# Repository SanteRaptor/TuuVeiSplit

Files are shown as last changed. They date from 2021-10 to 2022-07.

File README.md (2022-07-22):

# TuuVeiSplit v1.0 and v1.5 "Deluxe" 

A non-symmetrical non-standard (2x y & h with a b on the left side) TRRS split TKL keyboard with Vial support and ISO layout

Repository contains:

-Case STLs with extras

-Kicad PCB project files

-Firmware hex files

-QMK required files

-VIAL Json file

-PCB STL

-GERBERS!

(both versions compatible with eachothers parts)

Uses 2 arduino pro micros (or alternatives), 2 trough-hole TRRS ports and a TRRS cable for connecting the sides, trough-hole or smd 1n4148 diodes, 5 2U PCB stabilizers and 2 trough-hole resistors (chose to use 7.4k 1w but less wattage is fine).

Both versions tested to be fully working and keyboards have been built accordingly

Images

V1.5



V1.0



Acrylic case


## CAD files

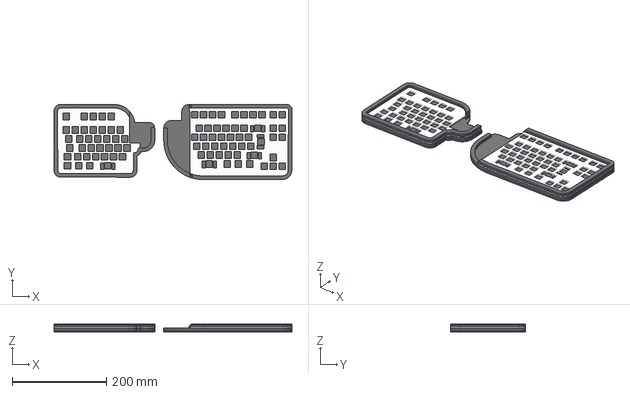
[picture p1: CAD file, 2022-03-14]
acryliccase.step
504.6 x 159.5 x 18.0 mm

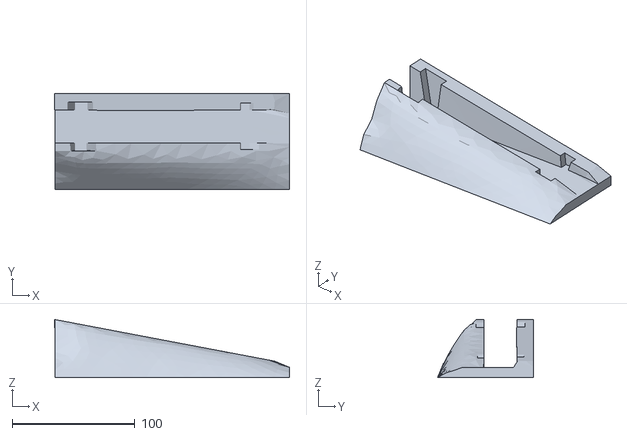
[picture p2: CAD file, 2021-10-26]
TUUVEICASE/Tuuright.stl
191.8 x 78.5 x 47.4

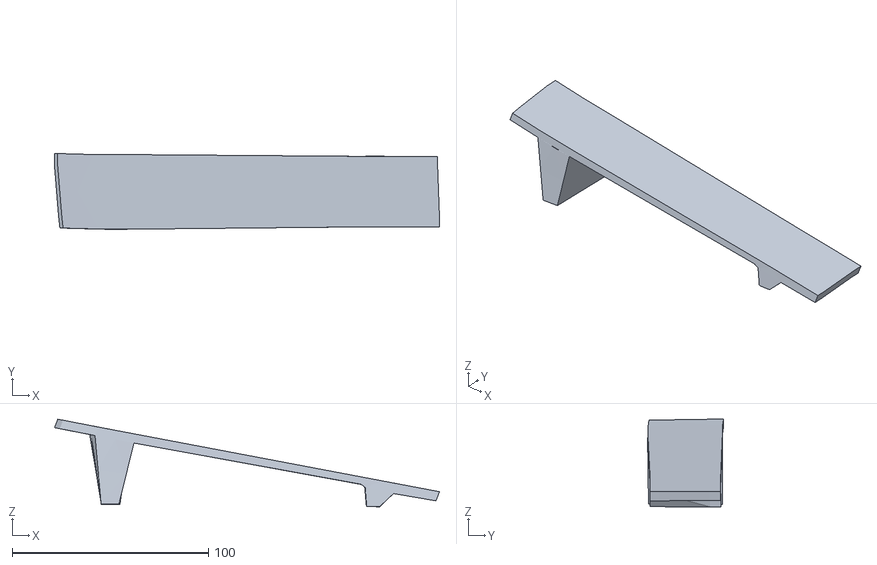
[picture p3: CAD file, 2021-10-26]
TUUVEICASE/TUUTUURIGHT.stl
196.4 x 38.7 x 44.7

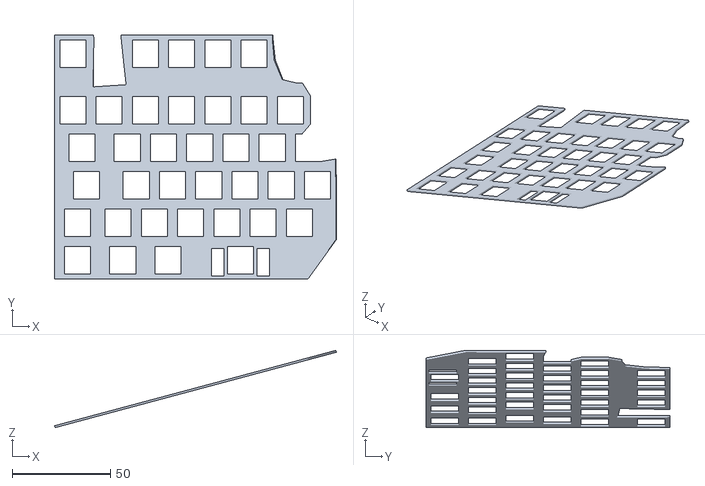
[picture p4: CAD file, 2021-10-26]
TUUVEICASE/plateleft.stl
143.2 x 123.8 x 39.3

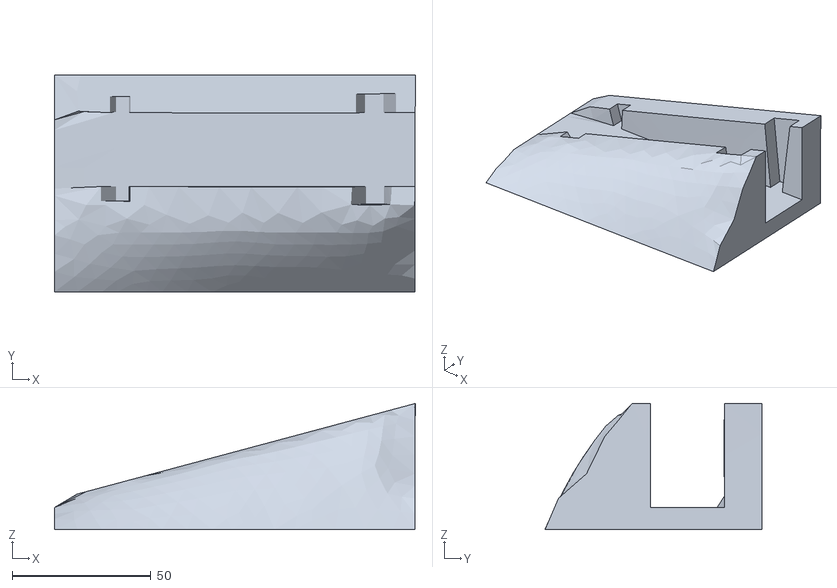
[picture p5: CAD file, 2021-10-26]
TUUVEICASE/Tuu.stl
130.3 x 78.5 x 45.6

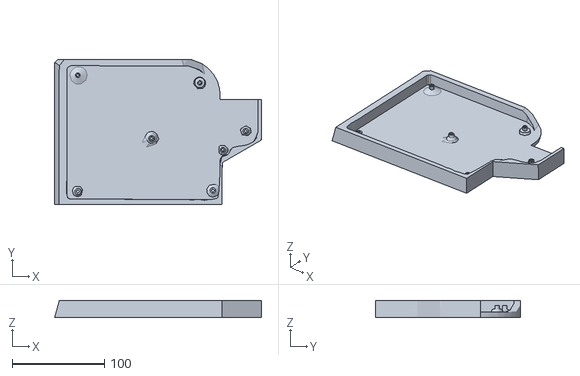
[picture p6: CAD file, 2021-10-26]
TUUVEICASE/TuuuuTuuTuu.stl
224.5 x 157.2 x 18.8

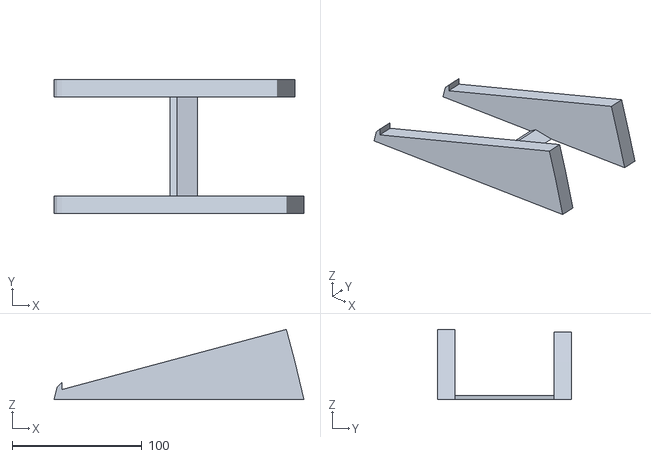
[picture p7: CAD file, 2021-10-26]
TUUVEICASE/TUUTUUTUU.stl
192.5 x 103.5 x 54.0

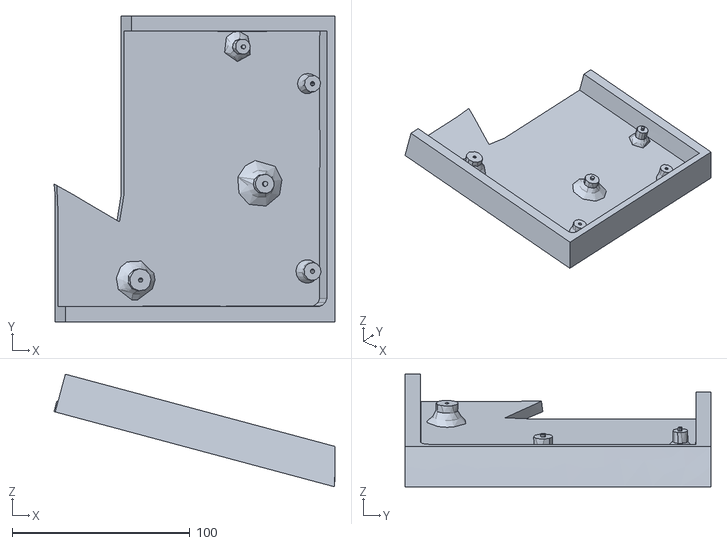
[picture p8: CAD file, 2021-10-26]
TUUVEICASE/TuuuuTuuTuuTuuuTuubottom.stl
157.9 x 171.9 x 63.3

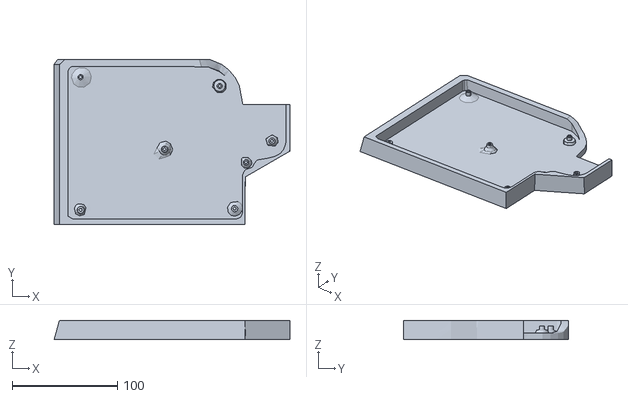
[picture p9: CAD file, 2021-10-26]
TUUVEICASE/TuuuuTuuTuuTuuu (1).stl
224.5 x 157.2 x 18.4

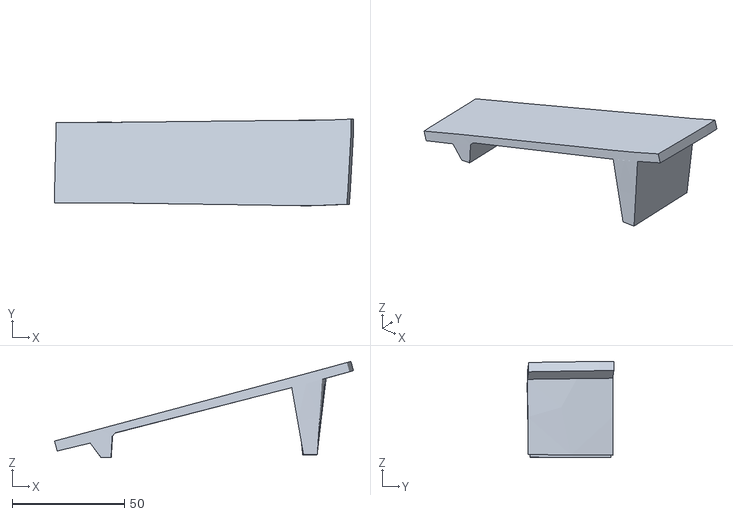
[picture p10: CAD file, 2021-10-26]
TUUVEICASE/TUUTUU.stl
133.4 x 38.7 x 42.9

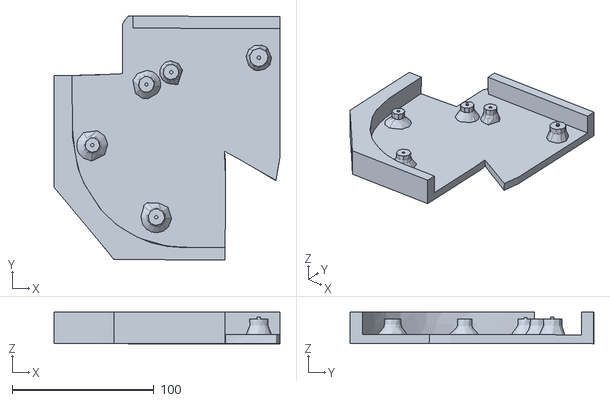
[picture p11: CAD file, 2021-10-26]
TUUVEICASE/TuuuuTuuTuuTuuuTuu.stl
159.5 x 172.0 x 22.2

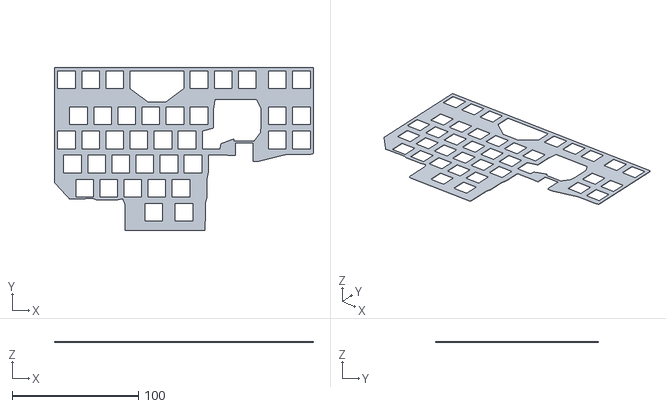
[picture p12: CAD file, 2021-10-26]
TUUVEICASE/Plate_2.stl
204.8 x 128.6 x 0.994

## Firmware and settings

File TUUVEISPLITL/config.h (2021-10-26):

/* Copyright 2021 REPLACE_WITH_YOUR_NAME
 *
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
 * You should have received a copy of the GNU General Public License
 * along with this program.  If not, see <http://www.gnu.org/licenses/>.
 */

#pragma once

#include "config_common.h"

/* USB Device descriptor parameter */
#define VENDOR_ID       0xFEED
#define PRODUCT_ID      0x0000
#define DEVICE_VER      0x0001
#define MANUFACTURER    %MANUFACTURER%
#define PRODUCT         TuuVeiSplitleft

/* key matrix size */
#define MATRIX_ROWS 11
#define MATRIX_COLS 9

/*
 * Keyboard Matrix Assignments
 *
 * Change this to how you wired your keyboard
 * COLS: AVR pins used for columns, left to right
 * ROWS: AVR pins used for rows, top to bottom
 * DIODE_DIRECTION: COL2ROW = COL = Anode (+), ROW = Cathode (-, marked on diode)
 *                  ROW2COL = ROW = Anode (+), COL = Cathode (-, marked on diode)
 *
 */
#define MATRIX_ROW_PINS { B6, B2, B3, B1, F7, F6 }
#define MATRIX_COL_PINS { B5, B4, E6, D7, D2, C6, D4 }

#define DIODE_DIRECTION ROW2COL
#define USE_I2C
#define MATRIX_ROW_PINS_RIGHT { B6, B2, B3, B1, F7, F5 }
#define MATRIX_COL_PINS_RIGHT { B5, B4, F6, D7, C6, D4, D2, D3, F4, E6 }
// generated by KBFirmware JSON to QMK Parser
// https://noroadsleft.github.io/kbf_qmk_converter/
#define DEBOUNCE 5
#define F_SCL 100000L
#define DYNAMIC_KEYMAP_LAYER_COUNT 3

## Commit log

2021-10-26 Added alot
    QMK stuff for building firmware, ready to go hex, kicad pcb project files for both sides, case files with some extras including 2 really poor plates, VIAL json file and STL of both pcbs
    [Plate_2.stl, TUUTUU.stl, TUUTUURIGHT.stl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]
2021-10-26 Added The gerbers
    [SplitH-B_Cu.gbr, SplitH-B_Mask.gbr, SplitH-B_Paste.gbr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]
2021-12-14 7z. Acrylic platestack case
    Plate stack case, Changes the mount style to Sandwhich layout. 6*3mm layers
    M3 Hex Mounting from top and bottom.
2022-02-04 The fully configured pcbs and project files
    Previous version didnt include the original finalized files
2022-03-14 Delete Platestack.7z
    Removing old acrylic case files because of a design fault
2022-03-14 Revisioned acrylic platestack case files
    Acrylic plate stack case, Changes the mount style to Sandwhich layout. 6*3mm layers
    Revision
    Version 12. Changed the Left side to accommodate space for the usb cable.
    Added Step file
    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
    [acryliccase.step]
2022-03-19 Add TuuVeiSplit 1.5 "Deluxe" case files
2022-03-19 1.5 Deluxe firmware and kicad files
2022-07-22 Update README.md
    Added picture of the acrylic case to readme

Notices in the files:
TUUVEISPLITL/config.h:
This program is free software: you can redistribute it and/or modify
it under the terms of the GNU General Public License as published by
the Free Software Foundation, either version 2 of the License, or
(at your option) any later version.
